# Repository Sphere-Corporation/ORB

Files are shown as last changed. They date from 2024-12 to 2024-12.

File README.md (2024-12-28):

<!-- PROJECT LOGO -->
<br />

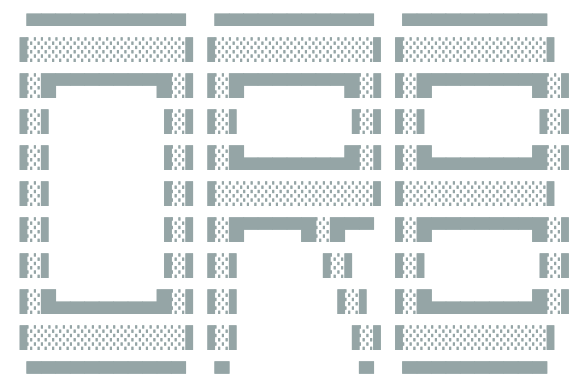
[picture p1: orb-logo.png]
Sphere-1 Corporation


  <p align="center">
    An Intel 1702A Emulator for the Sphere-1 CPU/2 Board
      </p>
<p align="center">
    <strong>
    "Optional ROM Board"
    </strong>
</p>
</div>

<!-- ABOUT THE PROJECT -->
## About The Project

Whilst building the reproduction CPU/2, I found (not a surprise) that some of the parts are becoming increasingly rare and expensive to find. One clear example of this is the Intel 1702A EPROMs.

These chips are integral to the CPU/2 board, as they contain the “Operating System” for the whole computer.

Project ORB, then, is a project to allow these chips to be simulated, and therefore not require expensive replacement chips.

## Contributing

Contributions are what make the open source community such an amazing place to learn, inspire, and create. Any contributions you make are **greatly appreciated**.

If you have a suggestion or a resource that would help me, or perhaps you see something I've got wrong, please create an Issue. 

<!-- LICENSE 
## License

Distributed under the MIT License. See `LICENSE.txt` for more information.
-->

<!-- CONTACT -->
## Contact

eMail [Andrew Shapton](mailto:alshapton@gmail.com)

<!-- ACKNOWLEDGMENTS -->
## Acknowledgments

I have to give my heartfelt thanks to Ben Zotto, who has been a sounding board for me throughout this project, answering my emails, and checking his Sphere-1 CPU/2 board to answer questions, and offering thoughts as to why things “were like they were” ! Without him, I would never have got as far as I have.

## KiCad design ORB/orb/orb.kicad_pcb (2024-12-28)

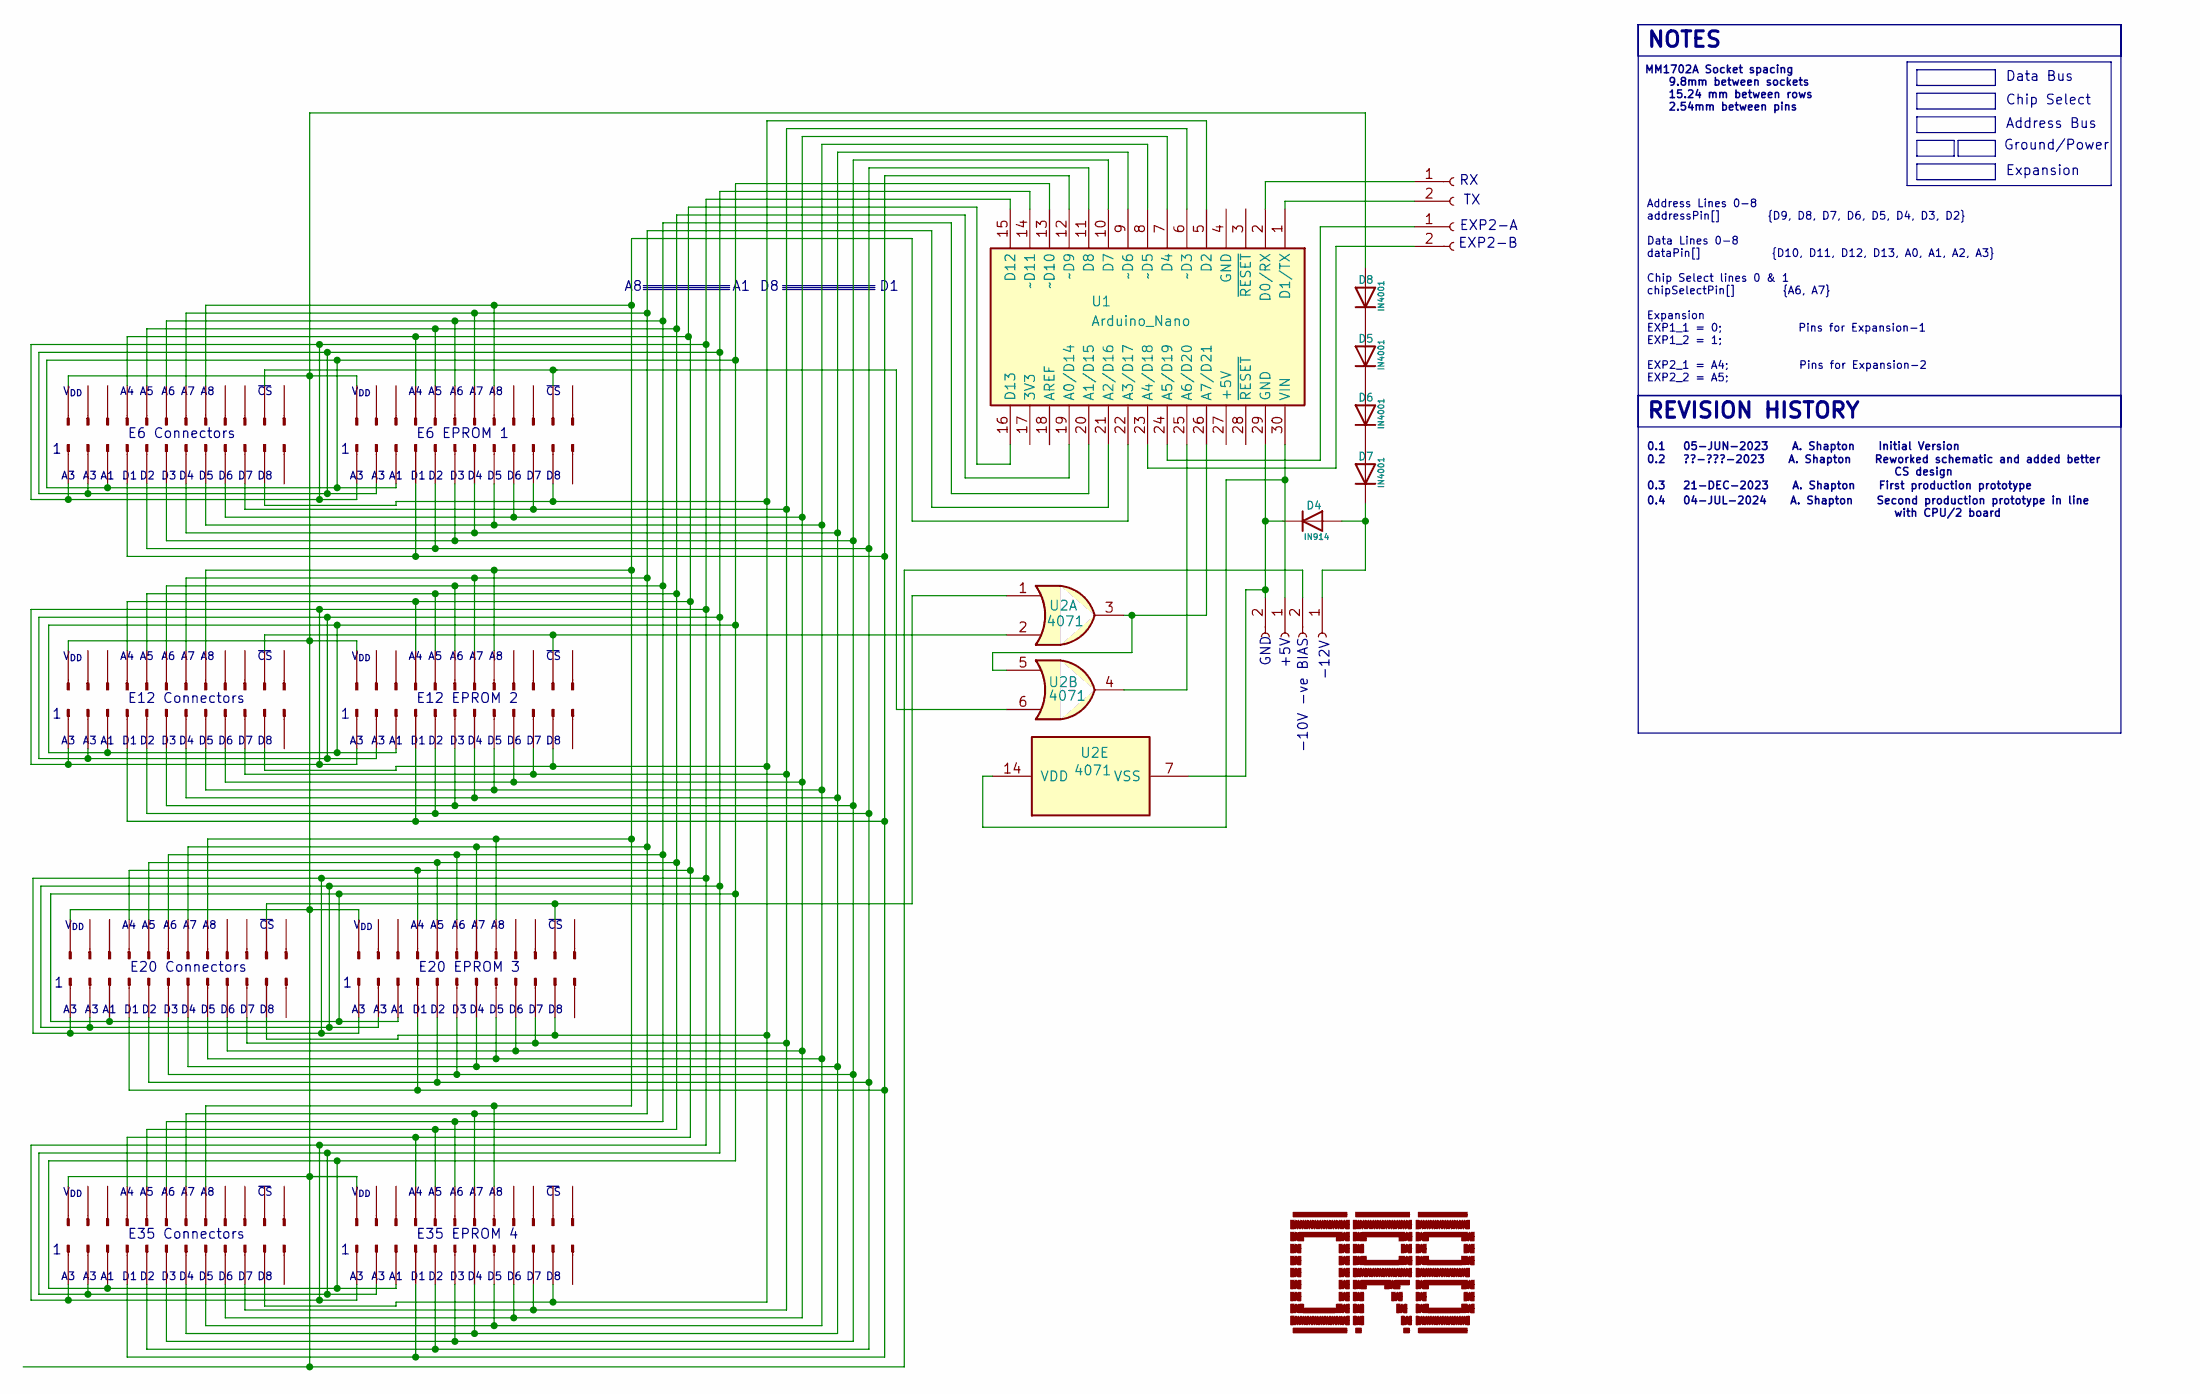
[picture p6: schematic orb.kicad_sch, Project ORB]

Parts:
D4: IN914; D_DO-41_SOD81_P10.16mm_Horizontal
D5, D6, D7, D8: IN4001; D_DO-41_SOD81_P10.16mm_Horizontal
E6-1, E6-3: E6-1C; PinHeader_1x12_P2.54mm_Vertical
E6-2, E6-4, E12-1, E12-2, E12-3, E12-4, E20-1, E20-2, E20-3, E20-4, E35-1, E35-2, E35-3, E35-4: Conn_01x12_Pin; PinHeader_1x12_P2.54mm_Vertical
J1, J2, J3, J4: Conn_01x02_Socket; PinSocket_1x02_P2.54mm_Vertical
U1: Arduino_Nano
U2: 4071; DIP-14_W7.62mm_Socket_LongPads

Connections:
unnamed: D4.2 (A), D7.1 (K), J4.1
unnamed: D4.1 (K), J1.2, U1.29 (GND), U2.7 (VSS)
unnamed: D5.2 (A), D8.1 (K)
unnamed: D5.1 (K), D6.2 (A)
unnamed: D6.1 (K), D7.2 (A)
unnamed: D8.2 (A), E6-1.1, E6-3.1, E12-1.1, E12-3.1, E20-1.1, E20-3.1, E35-1.1, E35-3.1, J4.2
unnamed: E6-1.11, E6-3.11, U2.6
unnamed: E6-1.4, E6-3.4, E12-1.4, E12-3.4, E20-1.4, E20-3.4, E35-1.4, E35-3.4, U1.16 (D13)
unnamed: E6-1.5, E6-3.5, E12-1.5, E12-3.5, E20-1.5, E20-3.5, E35-1.5, E35-3.5, U1.19 (A0/D14)
unnamed: E6-1.6, E6-3.6, E12-1.6, E12-3.6, E20-1.6, E20-3.6, E35-1.6, E35-3.6, U1.20 (A1/D15)
unnamed: E6-1.7, E6-3.7, E12-1.7, E12-3.7, E20-1.7, E20-3.7, E35-1.7, E35-3.7, U1.21 (A2/D16)
unnamed: E6-1.8, E6-3.8, E12-1.8, E12-3.8, E20-1.8, E20-3.8, E35-1.8, E35-3.8, U1.22 (A3/D17)
unnamed: E12-1.11, E12-3.11, U2.2
unnamed: E6-2.2, E6-4.2, E12-2.2, E12-4.2, E20-2.2, E20-4.2, E35-2.2, E35-4.2, U1.5 (D2)
unnamed: E6-2.3, E6-4.3, E12-2.3, E12-4.3, E20-2.3, E20-4.3, E35-2.3, E35-4.3, U1.6 (~D3)
unnamed: E6-2.4, E6-4.4, E12-2.4, E12-4.4, E20-2.4, E20-4.4, E35-2.4, E35-4.4, U1.7 (D4)
unnamed: E6-2.5, E6-4.5, E12-2.5, E12-4.5, E20-2.5, E20-4.5, E35-2.5, E35-4.5, U1.8 (~D5)
unnamed: E6-2.6, E6-4.6, E12-2.6, E12-4.6, E20-2.6, E20-4.6, E35-2.6, E35-4.6, U1.9 (~D6)
unnamed: E6-2.7, E6-4.7, E12-2.7, E12-4.7, E20-2.7, E20-4.7, E35-2.7, E35-4.7, U1.10 (D7)
unnamed: E6-2.8, E6-4.8, E12-2.8, E12-4.8, E20-2.8, E20-4.8, E35-2.8, E35-4.8, U1.11 (D8)
unnamed: E6-2.9, E6-4.9, E12-2.9, E12-4.9, E20-2.9, E20-4.9, E35-2.9, E35-4.9, U1.12 (~D9)
unnamed: E6-2.10, E6-4.10, E12-2.10, E12-4.10, E20-2.10, E20-4.10, E35-2.10, E35-4.10, U1.13 (~D10)
unnamed: E6-2.11, E6-4.11, E12-2.11, E12-4.11, E20-2.11, E20-4.11, E35-2.11, E35-4.11, U1.14 (~D11)
unnamed: E6-2.12, E6-4.12, E12-2.12, E12-4.12, E20-2.12, E20-4.12, E35-2.12, E35-4.12, U1.15 (D12)
unnamed: E20-1.11, E20-3.11, U2.1
unnamed: J1.1, U1.30 (VIN), U2.14 (VDD)
unnamed: J2.1, U1.2 (D0/RX)
unnamed: J2.2, U1.1 (D1/TX)
unnamed: J3.1, U1.24 (A5/D19)
unnamed: J3.2, U1.23 (A4/D18)
unnamed: U1.25 (A6/D20), U2.4
unnamed: U1.26 (A7/D21), U2.3, U2.5

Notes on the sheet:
V_{DD}
-12V
E20 EPROM 3
E6 Connectors
-10V -ve BIAS
Data Bus
E20 Connectors
EXP2-A
0.4 04-JUL-2024 A. Shapton Second production prototype in line with CPU/2 board
E35 Connectors
EXP2-B
Expansion
GND
NOTES
E12 EPROM 2
0.2 ??-???-2023 A. Shapton Reworked schematic and added better CS design
Address Bus
0.3 21-DEC-2023 A. Shapton First production prototype
Ground/Power
REVISION HISTORY
Address Lines 0-8 addressPin[] {D9, D8, D7, D6, D5, D4, D3, D2} Data Lines 0-8 dataPin[] {D10, D11, D12, D13, A0, A1, A2, A3} Chip Select lines 0 & 1 chipSelectPin[] {A6, A7} Expansion EXP1_1 = 0; Pins for Expansion-1 EXP1_2 = 1; EXP2_1 = A4; Pins for Expansion-2 EXP2_2 = A5;
E35 EPROM 4
E6 EPROM 1
0.1 05-JUN-2023 A. Shapton Initial Version
Chip Select
MM1702A Socket spacing 9.8mm between sockets 15.24 mm between rows 2.54mm between pins
E12 Connectors
+5V

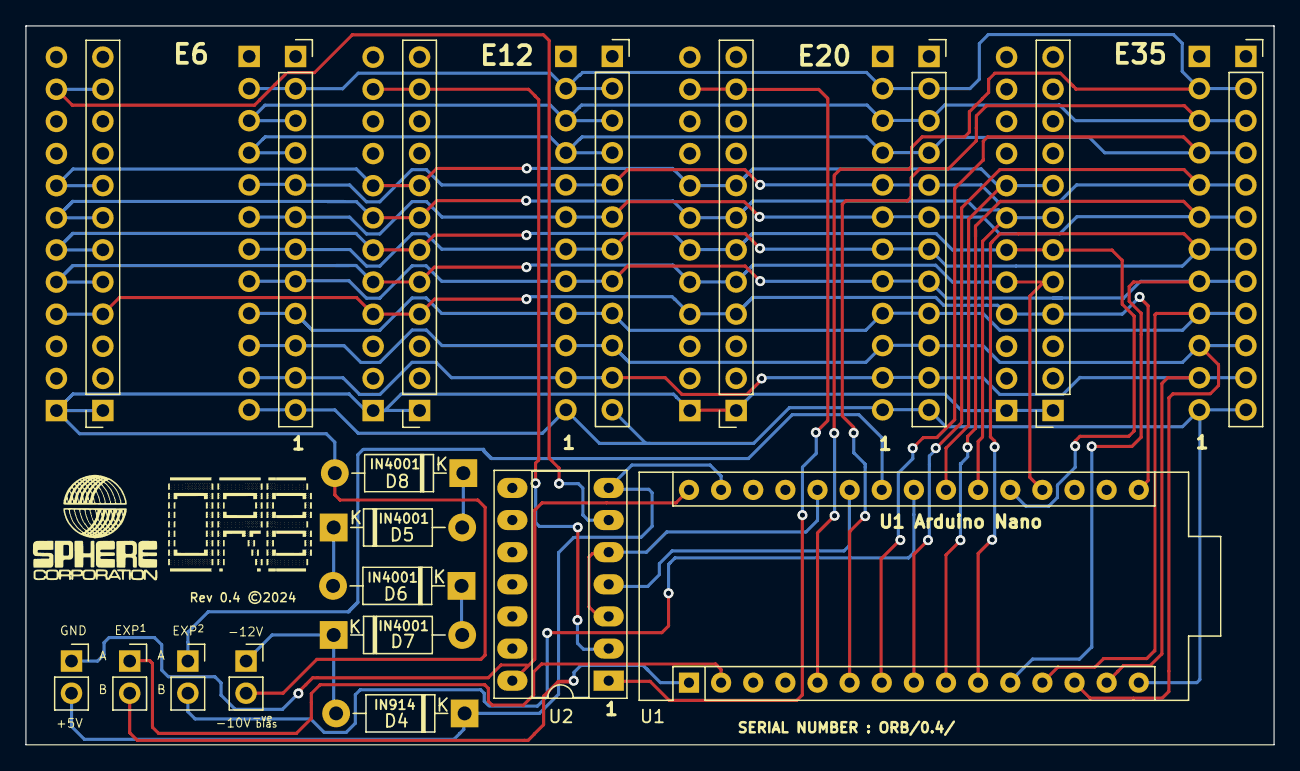
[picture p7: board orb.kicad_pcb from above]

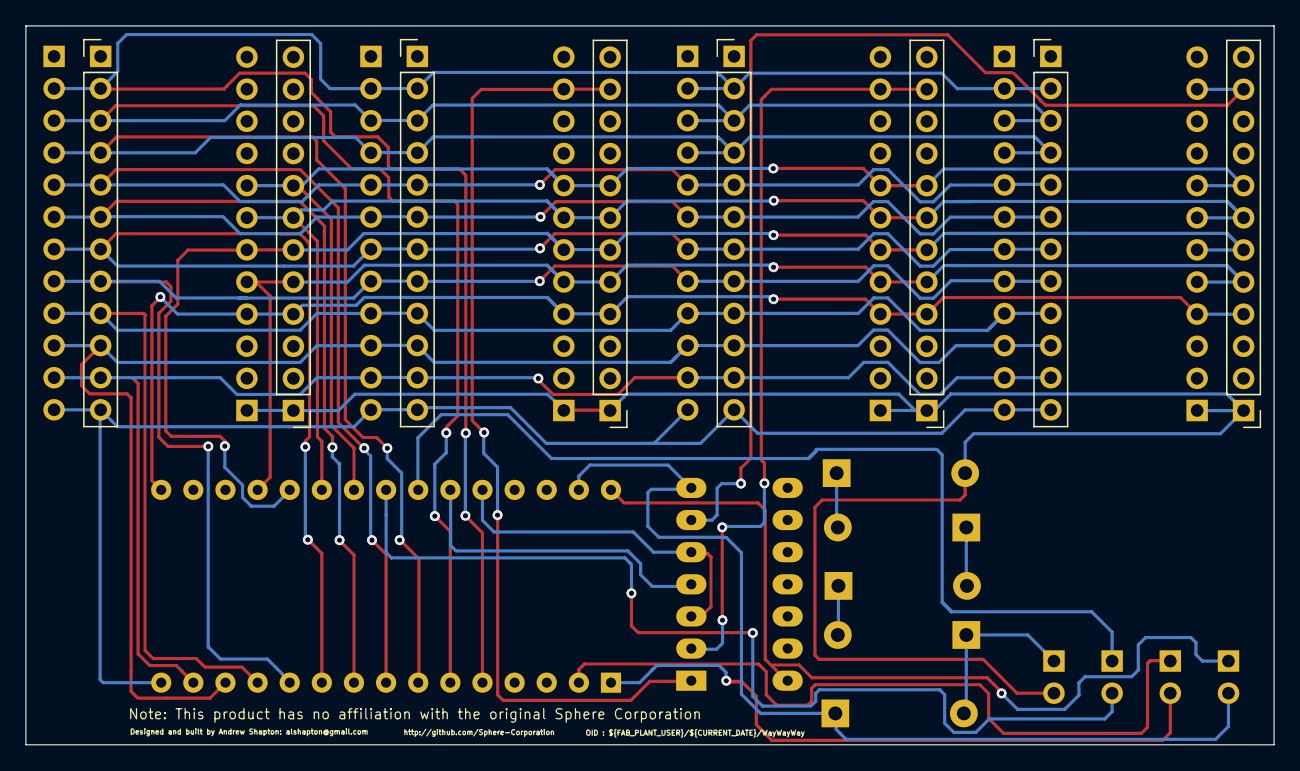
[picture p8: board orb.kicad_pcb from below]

Board: 2 copper layers, 98.7 x 56.8 mm, 27 parts (8 on the bottom side), 32 nets.

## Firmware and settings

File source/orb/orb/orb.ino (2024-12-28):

//
//           ▄▄▄▄▄▄▄▄▄▄▄  ▄▄▄▄▄▄▄▄▄▄▄  ▄▄▄▄▄▄▄▄▄▄
//          ▐░░░░░░░░░░░▌▐░░░░░░░░░░░▌▐░░░░░░░░░░▌
//          ▐░█▀▀▀▀▀▀▀█░▌▐░█▀▀▀▀▀▀▀█░▌▐░█▀▀▀▀▀▀▀█░▌
//          ▐░▌       ▐░▌▐░▌       ▐░▌▐░▌       ▐░▌
//          ▐░▌       ▐░▌▐░█▄▄▄▄▄▄▄█░▌▐░█▄▄▄▄▄▄▄█░▌
//          ▐░▌       ▐░▌▐░░░░░░░░░░░▌▐░░░░░░░░░░▌
//          ▐░▌       ▐░▌▐░█▀▀▀▀█░█▀▀ ▐░█▀▀▀▀▀▀▀█░▌
//          ▐░▌       ▐░▌▐░▌     ▐░▌  ▐░▌       ▐░▌
//          ▐░█▄▄▄▄▄▄▄█░▌▐░▌      ▐░▌ ▐░█▄▄▄▄▄▄▄█░▌
//          ▐░░░░░░░░░░░▌▐░▌       ▐░▌▐░░░░░░░░░░▌
//           ▀▀▀▀▀▀▀▀▀▀▀  ▀         ▀  ▀▀▀▀▀▀▀▀▀▀
//

//          Project ORB
//.                      "Optional ROM Board"
//
//          An Arduino-based emulator for the
//          4 x Intel 1702A TTL EPROM chips
//          and the "OS" for the SPHERE-1 Computer
//
//          Author:       Andrew Shapton
//
//          Credits:      Ben Zotto for the ROM image binary
//
//          Revision:     0.1         Initial Release - no board fab
//                        0.2         Reduced number of pins for chip select by constructing a 4:2 Binary Encoder
//                        0.3         N/A
//                        0.4         Released to go with 0.4 of the board


// Program Size Information
// Status       sketch    %         Global Vars   %
// Baseline     7088      23%       298           14%
// DEBUG 1      7088      23%       298           14%
// DEBUG 0      5826      18%        83            4%

// Define DEBUG settings
#define DEBUG 0

#if DEBUG == 1
#define debug(txt) Serial.println(txt);
#define debugbegin() Serial.begin(9600); // Any baud rate should work
#else
#define debug(txt) 
#define debugbegin()
#endif 

// Include PDS V3N ROM image
#include "pds-v3n.h"

// Include functions
#include "functions.h"

// Include pin layouts for interface to Arduino Nano
#include "pinlayouts.h"

// Constants
constexpr int CHIP_SIZE = 256;            // Size of 1702A EPROM chip in bytes

constexpr int numberOfAddressPins = 8;    // Number of pins on the address bus
constexpr int numberOfChipSelectPins = 2; // Number of pins on the CS line (Chip Select)
constexpr int numberOfDataPins = 8;       // Number of pins on the data bus

String binaryString = "";                 // Empty string to store a string representation of a binary number
char char_array[numberOfAddressPins] = {};// Character array to store address from the address bus
int val[8] = {};                          // General purpose array to store 8 bits
int loc;                                  // Location within a ROM image   
int value;                                // value of a specified location in a ROM image
int cs = -1;                              // initialise current CS to -1 - indicating no chip has been selected, so locate ROM

void setup() {
  debugbegin()

  // Initialise the Chip Select pins
  for (int thisPin = 0; thisPin < numberOfChipSelectPins; thisPin++) {
    pinMode(chipSelectPin[thisPin], INPUT_PULLUP);    // sets the digital pin as input with a PULLUP
  } 
    // Initialise the address bus pins
  for (int thisPin = 0; thisPin < numberOfAddressPins; thisPin++) {
    pinMode(addressPin[thisPin], INPUT_PULLUP);    // sets the digital pin as input with a PULLUP
  }

  // Write a LOW signal to the Data Lines (thus initialising them to an analogue read status)
  for (int thisPin = 0; thisPin < numberOfDataPins; thisPin++) {
    pinMode(dataPin[thisPin], OUTPUT);    // sets the digital pin as output 
    analogWrite(dataPin[thisPin], 255);
  }
}

void loop() {

  // Acquire the selected chip 
  cs = chipselectBC(chipSelectPin);
  if (cs > 0)
    {
      // If there is a valid chip selected (there should never not be)
      for (int thisVal = 0; thisVal < numberOfAddressPins; thisVal++) {
        val[thisVal] = 0;
      }

      // initialise the value of a string to null to receive the binary address from the address bus
      binaryString = "";
      for (int readAddressPin = 0; readAddressPin < numberOfAddressPins; readAddressPin++)
      {
        val[readAddressPin] = not(digitalRead(addressPin[readAddressPin]));   // read this input pin
        String pin = String(val[readAddressPin]);
        binaryString = binaryString + pin;
      }

    // Terminate the string
    binaryString = binaryString + "\0";
  
    // Convert the binary string to a character array, and then on to a decimal address
    binaryString.toCharArray(char_array, numberOfAddressPins+1);
    loc = bin2dec(char_array);

    // Retrieve value from ROM image
    int address = loc + (((cs -1) * CHIP_SIZE));    // Ensure the selected chip is taken into consideration
    value = pgm_read_byte_near( &(ROM[address]) );  // Note that the ROM image is stored in program memory
    
    // Left pad with zeroes to length of data bus
    String valueBinary = (padleft(String(value, BIN),numberOfDataPins,"0"));

    // Debug only
    debug("CS " + String(cs) + " / LOC(" + loc + "/" + binaryString + " ) / ABS " + String(address) + " / VAL(" + value + "/" + valueBinary + ")");
    
    // Write an output signal to each of the 8 data lines
    for (int thisPin = 0; thisPin < numberOfDataPins; thisPin++) 
      {
        char thisBin = valueBinary.charAt(thisPin);
        if (thisBin == '1')
          {      
            analogWrite(dataPin[thisPin], 255);
          }
        else
          {
            analogWrite(dataPin[thisPin], 0);
          }
      }
    }
}

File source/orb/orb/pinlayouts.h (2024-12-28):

constexpr int addressPin[]  = {9, 8, 7, 6, 5, 4, 3, 2};       //  Address Lines 0-8 

constexpr int dataPin[]  = {10, 11, 12, 13, A0, A1, A2, A3} ; // Data Lines 0-8

constexpr int chipSelectPin[]  = {A6, A7};                    // Chip Select lines 0 & 1

// Define pins for expansion
constexpr int EXP1_1 = 0;                                     // Pins for Expansion-1 
constexpr int EXP1_2 = 1; 

constexpr int EXP2_1 = A4;                                    // Pins for Expansion-2
constexpr int EXP2_2 = A5;

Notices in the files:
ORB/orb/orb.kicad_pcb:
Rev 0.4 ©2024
